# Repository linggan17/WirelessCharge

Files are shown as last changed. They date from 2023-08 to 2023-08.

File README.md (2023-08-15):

# WirelessCharge
本仓库是一个基于IP6829方案的无线充电器。

整机BOM包含如下：

1，主板PCBA：（使用立创EDA绘制：https://oshwhub.com/linggan/ip6829_2023）

2，3D外壳

3，磁环（购买参考链接：https://item.taobao.com/item.htm?spm=a1z09.2.0.0.fcc42e8dMrpgfO&id=659596142641&_u=f20m052qc46f）

4，φ3的螺丝

5，无线充电线圈：（购买参考链接：https://item.szlcsc.com/417711.html）

备注：IP6826和IP6829是pin to pin的。我用IP6829验证的。

避坑：嘉立创的IP6826是白片，无固件。不要买！

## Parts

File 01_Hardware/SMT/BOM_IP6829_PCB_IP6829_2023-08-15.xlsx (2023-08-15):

No. | Quantity | Comment | Designator | Footprint | Value | Manufacturer Part | Manufacturer | Supplier Part | Supplier
1 | 4 | 100nF | C1,C3,C13,C14 | C1206 |  | 1206N104J500CT | Walsin(华新科) | C170182 | LCSC
2 | 1 | 100nF | C2 | C0805 |  | 0805B104K500NT | FH(风华) | C38141 | LCSC
3 | 3 | 15nF | C4,C5,C10 | C0402 |  | CC0402KRX7R9BB153 | YAGEO(国巨) | C114405 | LCSC
4 | 2 | 100nF | C7,C16 | C0402 |  | CC0402KRX7R9BB104 | YAGEO(国巨) | C131394 | LCSC
5 | 1 | 2.2nF | C8 | C0402 |  | 0402B222K500NT | FH(风华) | C1531 | LCSC
6 | 1 | 2.2uF | C11 | C0603 |  | 0603B225K160NT | FH(风华) | C43922 | LCSC
7 | 2 | 22uF | C12,C17 | C0805 |  | 0805X226M250NT | FH(风华) | C129303 | LCSC
8 | 1 | 15nF | C15 | C0402 |  | GCM155R71H153KA55D | muRata(村田) | C430702 | LCSC
9 | 1 | 6.3uH（无线充电线圈） | L1 | L1210 |  | NLV32T-270J-PF | CND | C424421 | LCSC
10 | 2 | LED-0603_G | LED1,LED2 | LED0603_GREEN |  | 19-217/GHC-YR1S2/3T | EVERLIGHT(台湾亿光) | C72043 | LCSC
11 | 2 | 1kΩ | R1,R13 | R0402 |  | 0402WGF1001TCE | UNI-ROYAL(厚声) | C11702 | LCSC
12 | 2 | 100kΩ | R4,R11 | R0402 |  | 0402WGF1003TCE | UNI-ROYAL(厚声) | C25741 | LCSC
13 | 1 | 33kΩ | R5 | R0402 |  | 0402WGF3302TCE | UNI-ROYAL(厚声) | C25779 | LCSC
14 | 1 | 10kΩ | R6 | R0402 |  | 0402WGF1002TCE | UNI-ROYAL(厚声) | C25744 | LCSC
15 | 1 | PA1206FRF470R02L | R7 | R1206 |  | PA1206FRF470R02L | YAGEO(国巨) | C728292 | LCSC
16 | 2 | 0R | R9,R14 | R0402 |  | RC0402FR-070RL | YAGEO(国巨) | C106231 | LCSC
17 | 1 | 3.3kΩ | R10 | R0603_NEW |  | 0603WAF3301T5E | UNI-ROYAL(厚声) | C22978 | LCSC
18 | 1 | RNTC | R12 | R0805 |  | SDNT2012X104F4250FTF | Sunlord(顺络) | C95970 | LCSC
19 | 1 | IP6826 QFN32 | U1 | QFN-32_L5.0-W5.0-P0.50-BL-EP3.8 |  | IP6826/IP6829 | INJOINIC(英集芯) | C2921390 | LCSC
20 | 1 | IN5819-OD123 | U2 | SOD-123_L2.7-W1.6-LS3.7-RD-1 |  | IN5819-OD123 | null | C9900014277 | LCSC
21 | 1 | TYPEC-302-ARP16SC16 | USB1 | USB-TYPE-C-SMD_TYPEC-302-ARP16SC16 |  | TYPEC-302-ARP16SC16 | XUNPU(讯普) | C5454920 | LCSC

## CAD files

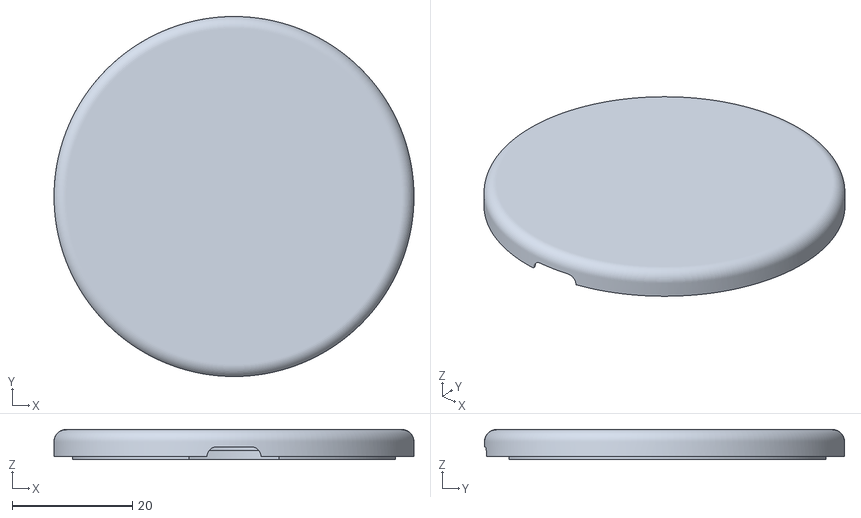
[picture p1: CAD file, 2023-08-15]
04_Model/3D打印文件/上壳_最终.stl
60.0 x 60.0 x 5.00

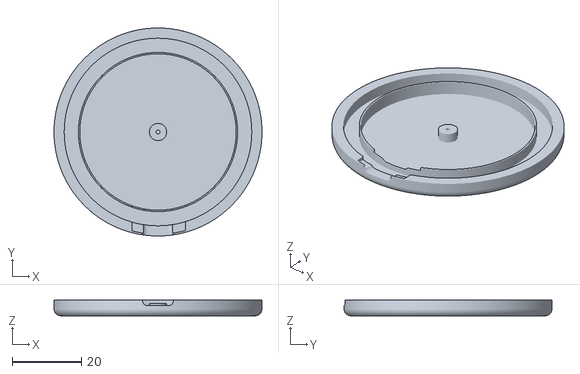
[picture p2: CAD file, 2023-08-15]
04_Model/3D打印文件/下壳_最终.stl
60.0 x 60.0 x 4.50

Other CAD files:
04_Model/PCBA_3D/零部件PCBA.step
04_Model/源文件/无线充电3D外壳.step

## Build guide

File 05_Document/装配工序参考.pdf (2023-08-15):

# 装配工序

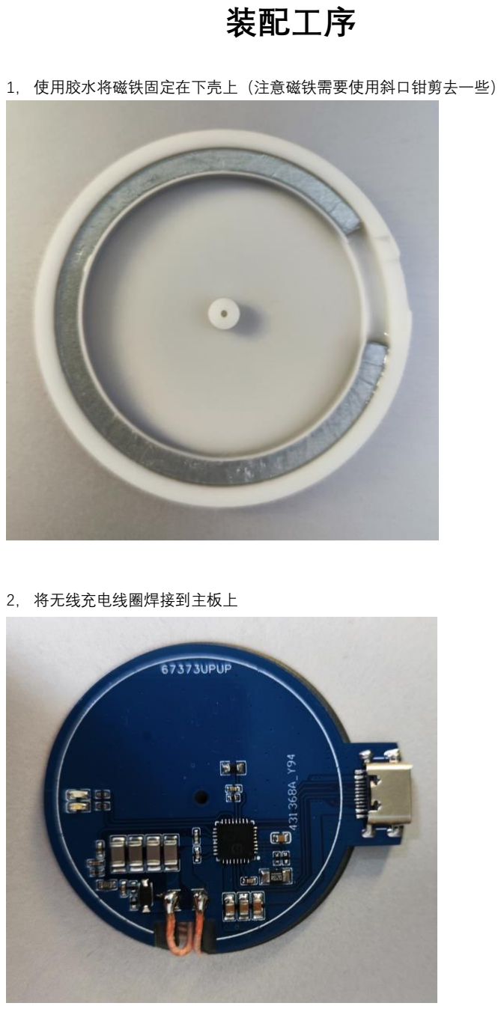
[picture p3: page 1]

1， 使用胶水将磁铁固定在下壳上（注意磁铁需要使用斜口钳剪去一些）

2， 将无线充电线圈焊接到主板上

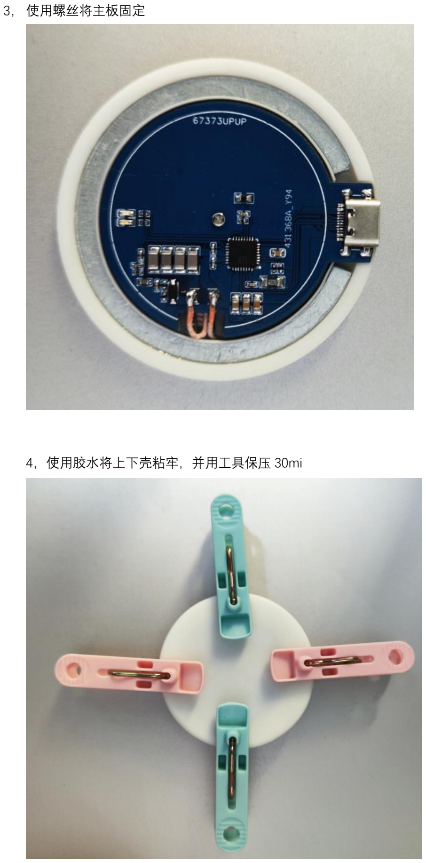
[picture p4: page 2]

3， 使用螺丝将主板固定

4，使用胶水将上下壳粘牢，并用工具保压 30mi
